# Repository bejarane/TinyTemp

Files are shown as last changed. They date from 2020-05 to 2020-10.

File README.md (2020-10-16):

# ATtiny85 OLED Thermometer
## Summary
This example shows the implementation for an OLED display, DHT22 thermometer and the usage of sleep for low power consumption.
The parameters shown are temperature, humidity and heat index.

The libraries required are:
- [DHT sensor library](https://github.com/adafruit/DHT-sensor-library/) from Adafruit.
- [Tiny4kOLED](https://github.com/datacute/Tiny4kOLED/) from datacute. 

## How it works
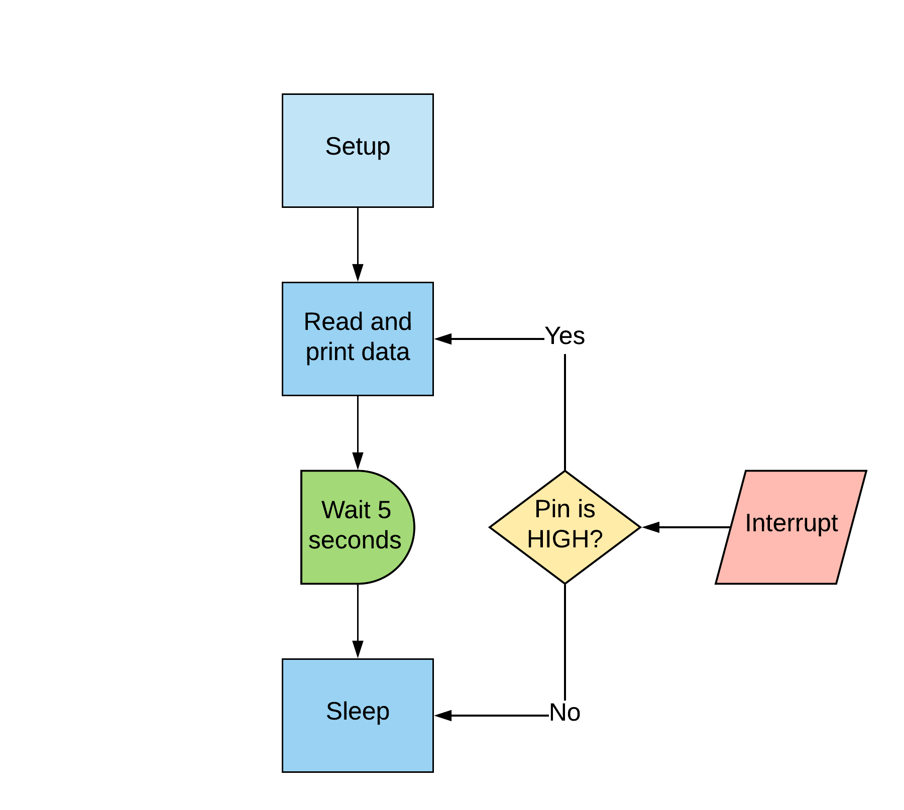
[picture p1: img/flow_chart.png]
flow chart


As described above, the program basically runs on a loop but most of the time it is under the sleep state. As soons as an interrupt is triggered the program reads the DHT sensor and holds the information on screen for 5 seconds. Then it resumes the sleep state until the next interrupt.

## Circuit

Two main circuits are necessary. One circuit to program the ATtiny and another one for the thermometer itself.

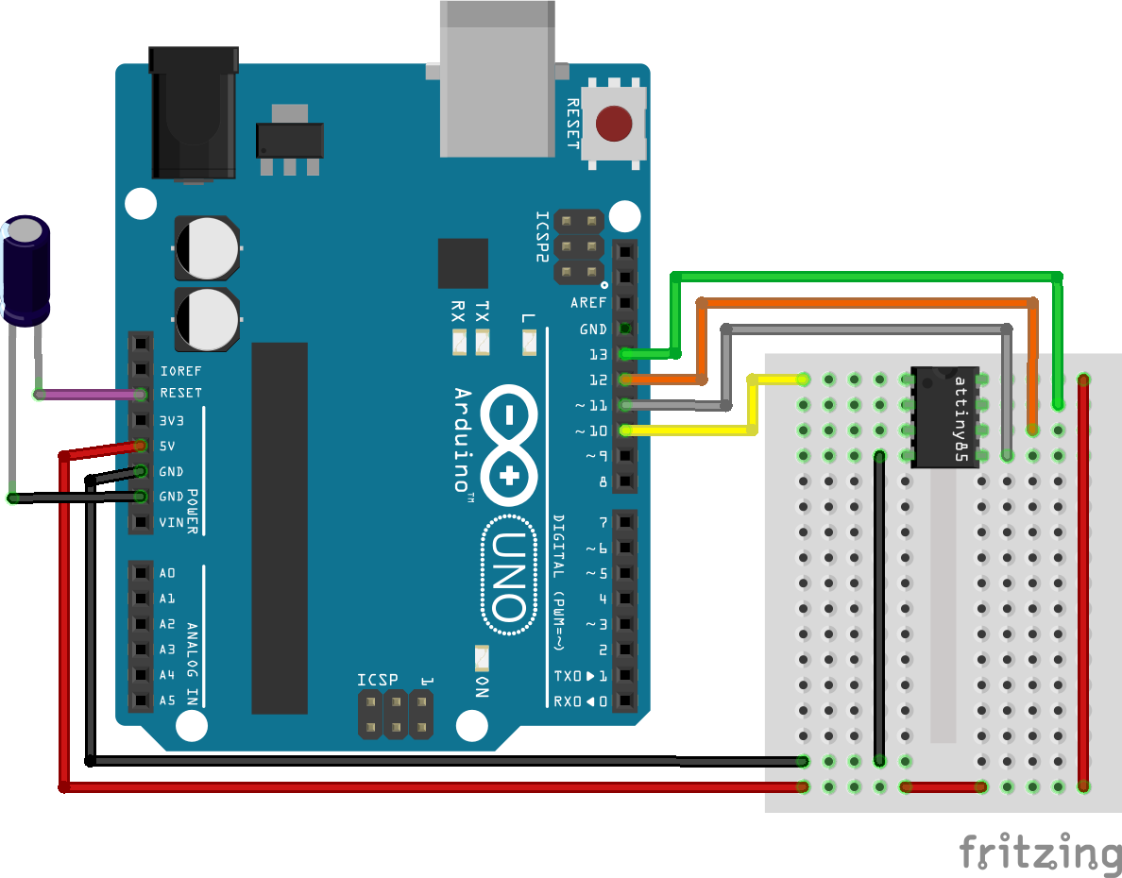
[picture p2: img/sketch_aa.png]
Programmer circuit


The capacitor on the Arduino's reset pin is only necessary while programming the ATtiny. It must be taken off when loading the Arduino with the Arduino as ISP sketch.

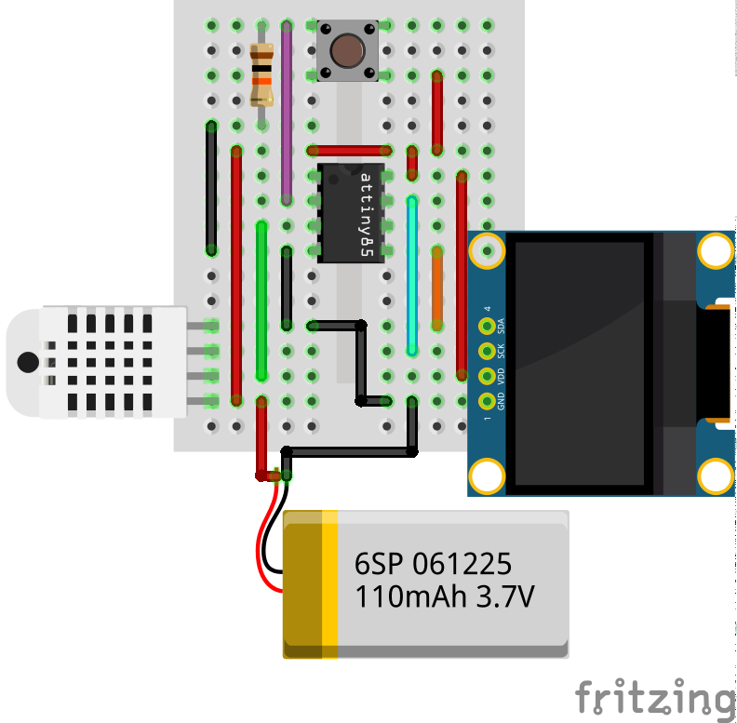
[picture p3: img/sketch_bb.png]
Thermometer circuit


DHT sensor is connected on pin 4 of the ATtiny (pinout provided below). The SDA and SCL pins use pin 0 and 2 of the ATtiny respectively.

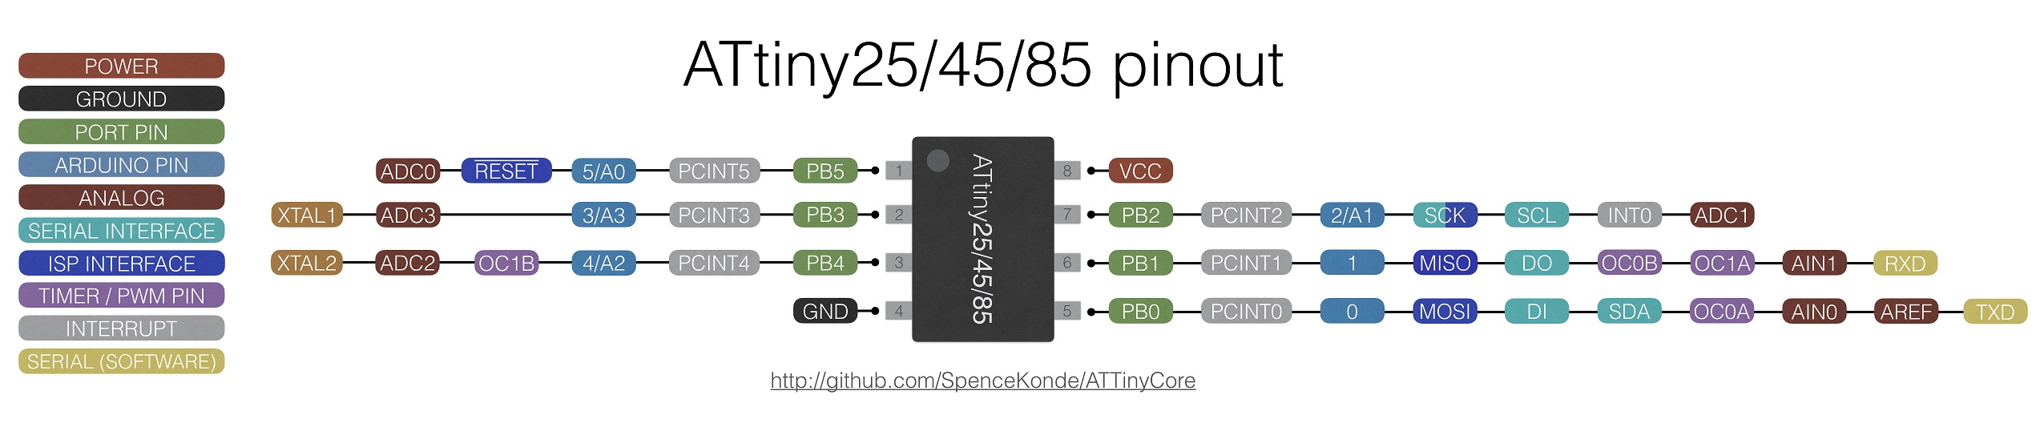
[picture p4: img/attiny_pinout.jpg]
ATtiny85 pinout

ATtiny85 pinout (source https://github.com/SpenceKonde/ATTinyCore)

## Programming
- Use SpenceKonde ATTinycore board
- Board must be configured without BOD or bootloader. Also, 8MHz clock speed is recommended for proper I2C communication.

## Results
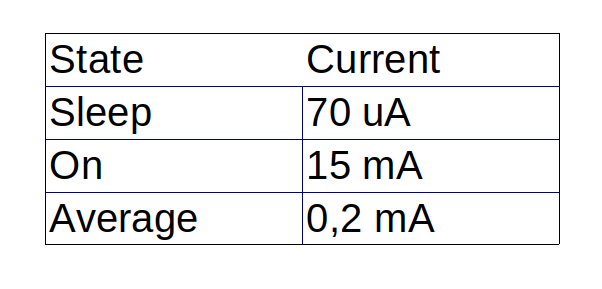
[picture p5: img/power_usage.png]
Tested comsuption
- Power consumption is very low. Avereage current is 200uA. .
- Energy consumption results defer from [Technoblogy](http://www.technoblogy.com/show?KX0&fbclid=IwAR0qujeHHnLwCLaDrUGe500OKDWC_zPyXkE4ueqHWGD06zeFv5_O4Y1dK-k) results. It could be due to the fact that the OLED and DHT are not disconnected from power bus. It could be resolved by powering them from the left free pin.
Technoblogy consumption ratings

## Updates
- Device has been running for more than 6 months of uninterrupted discharge. It is not used very often, maybe once or twice a day, but the battery still holds enough charge for the ATtiny and periphericals to operate. During design I estimated a maximum charge-life of 2 years if not used. I would be not amazed if it survives another 6 or 12 months until the Lithium battery dies by self discharge.

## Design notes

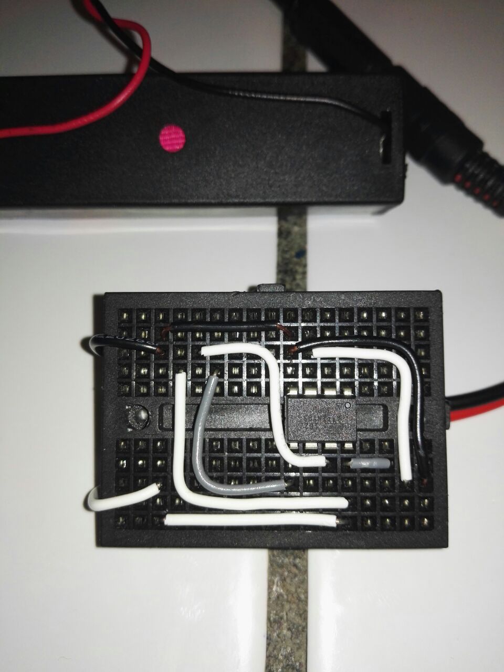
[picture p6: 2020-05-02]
img/photo_b.jpg

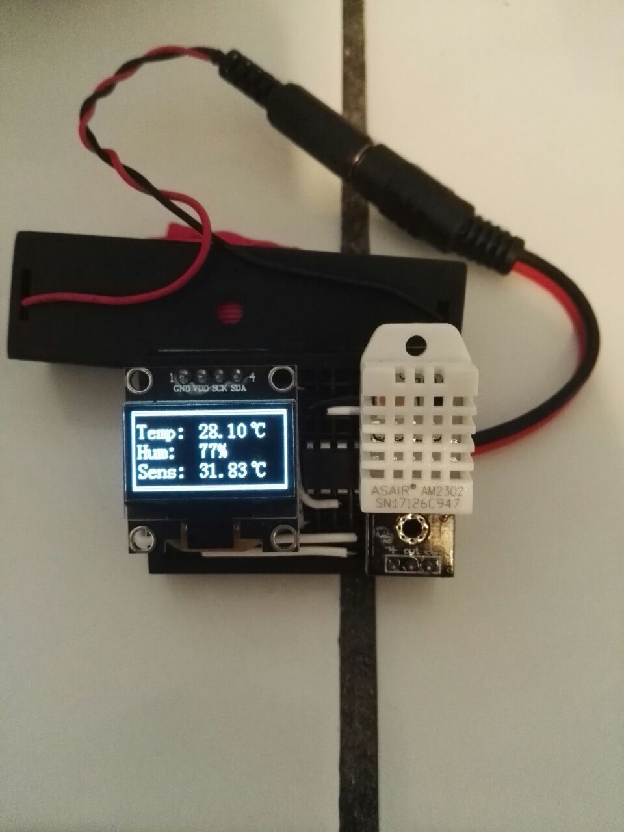
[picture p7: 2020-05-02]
img/photo_a.jpg

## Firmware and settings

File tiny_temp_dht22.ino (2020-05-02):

#include <DHT.h>
#include <Tiny4kOLED.h>
#include <avr/interrupt.h>
#include <avr/sleep.h>


#define I_PINB PCINT3
#define I_PIN PB3
#define I_VECTOR PCINT0_vect

#define adc_disable() (ADCSRA &= ~(1<<ADEN)) //disable ADC converter


#define DHTPIN 4
#define DHTTYPE DHT22

DHT dht(DHTPIN,DHTTYPE);

const uint8_t width = 128;
const uint8_t height = 64;

volatile bool turned = false;


/*
*
* Interrupt handler
*
*/
ISR(PCINT_VECTOR){ //interrupt always recovers from sleep
  if( digitalRead(I_PIN) == HIGH ) {
    turned = true; //set the flag to redraw screen again
  }
}


void setup() {
  cli(); //turn off interrupts

  PCMSK |= (1 << I_PINB);
  GIMSK |= (1 << PCIE);
  pinMode(I_PIN, INPUT);

  sei(); //turn on interrupts

  adc_disable(); //save power turning off the converter
  set_sleep_mode(SLEEP_MODE_PWR_DOWN); //set the type of sleep to deep sleep

  
  oled.begin(width, height, sizeof(tiny4koled_init_128x64br), tiny4koled_init_128x64br); //start oled object
  oled.setFont(FONT8X16); //this font looks better than the other one
  drawScreen();
  oled.on();
  
  delay(2000);
  dht.begin();
  
  turned = true; //flag for drawing screen
}

void sleep(){
  sleep_enable();
  sleep_cpu();
}

void loop() {
  if (turned){
    cli(); //turn off interrupts
    oled.on();

    float h = dht.readHumidity();//false read to reset dht cache
    delay(2200);//wait dht to load
    h = dht.readHumidity();
    float t = dht.readTemperature();
    float i = dht.computeHeatIndex(t,h,false);
  
  
    oled.setCursor(55, 1);
    oled.print(t);
    oled.print("~C");
    oled.setCursor(55, 3);
    oled.print(h,0);
    oled.print("%");
    oled.setCursor(55,5);
    oled.print(i);
    oled.print("~C"); //the ~ symbol was changed on the library to look like a ° degree symbol
    delay(5000); //show for 5 seconds
    oled.off();
    
    turned = false;
    sei();//attach interrupts again
  }

  sleep(); //always go to sleep at the end
  
  
}

void drawScreen() {
  //draws the frame an the main text
  
  for (uint8_t y = 0; y < 8; y++) {
    oled.setCursor(0, y);
    oled.startData();
    for (uint8_t x=0; x<128; x += 2) {
      oled.sendData(0b10101010);
      oled.sendData(0b01010101);
    }
    oled.endData();
  }

  oled.setCursor(0, 0);
  oled.startData();
  oled.sendData(0b11111111);
  oled.repeatData(0b00000101, width - 2);
  oled.sendData(0b11111111);
  oled.endData();

  for (uint8_t y = 1; y < (height - 8) / 8; y++) {
    oled.setCursor(0, y);
    oled.startData();
    oled.sendData(0b11111111);
    oled.repeatData(0b00000000, width - 2);
    oled.sendData(0b11111111);
    oled.endData();
  }

  oled.setCursor(0, (height - 8) / 8);
  oled.startData();
  oled.sendData(0b11111111);
  oled.repeatData(0b10100000, width - 2);
  oled.sendData(0b11111111);
  oled.endData();

  oled.setCursor(4, 1);
  oled.print("Temp:");
  oled.setCursor(4, 3);
  oled.print("Hum:");
  oled.setCursor(4,5);
  oled.print("Sens:");
}
